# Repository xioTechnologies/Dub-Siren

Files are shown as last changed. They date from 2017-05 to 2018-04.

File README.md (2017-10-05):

# Dub Siren

A monophonic synthesiser comprised of an LFO, VCO, and Delay.  The synthesiser is controlled by 9 potentiometers and 3 buttons.  Configurations can be stored to 1 of 10 preset keys.  Pressing a preset key will override the potentiometers and buttons with the stored configuration.

The processor used is [PIC32MZ](http://www.microchip.com/wwwproducts/en/PIC32MZ2048EFH064).  This is a 32-bit device with a FPU, 512 KB of RAM, 2 MB of program space, running at 252 MHz.  The processor is deliberately over-spec'd to simplify development and allow new ideas to be explored in the future.  The [DAC](https://www.cirrus.com/products/cs4354/) is a 24-bit 192 kHz stereo device configured for 96 kHz mono.

## Synthesiser elements

##### LFO
- Waveforms: sine, triangle, sawtooth, square, stepped triangle, stepped sawtooth
- Shape: adjusts waveform shape
- Frequency: 0 Hz to 15 Hz
- Amplitude: -1 to +1
- Gate control: enable/disable (automatically opens gate after one cycle)

##### VCO
- Waveforms: sine, triangle, sawtooth, square, pulse, 1-bit noise
- Frequency: 0.5 Hz to 5 kHz

##### Delay
- Time: 0 s to 1.33 s
- Feedback: 0% to 100%
- Filter: 3rd-order low-pass with adjustable corner frequency, all-pass (filter disabled), 3rd-order high-pass with adjustable corner frequency

## User instructions (etched on the back panel)

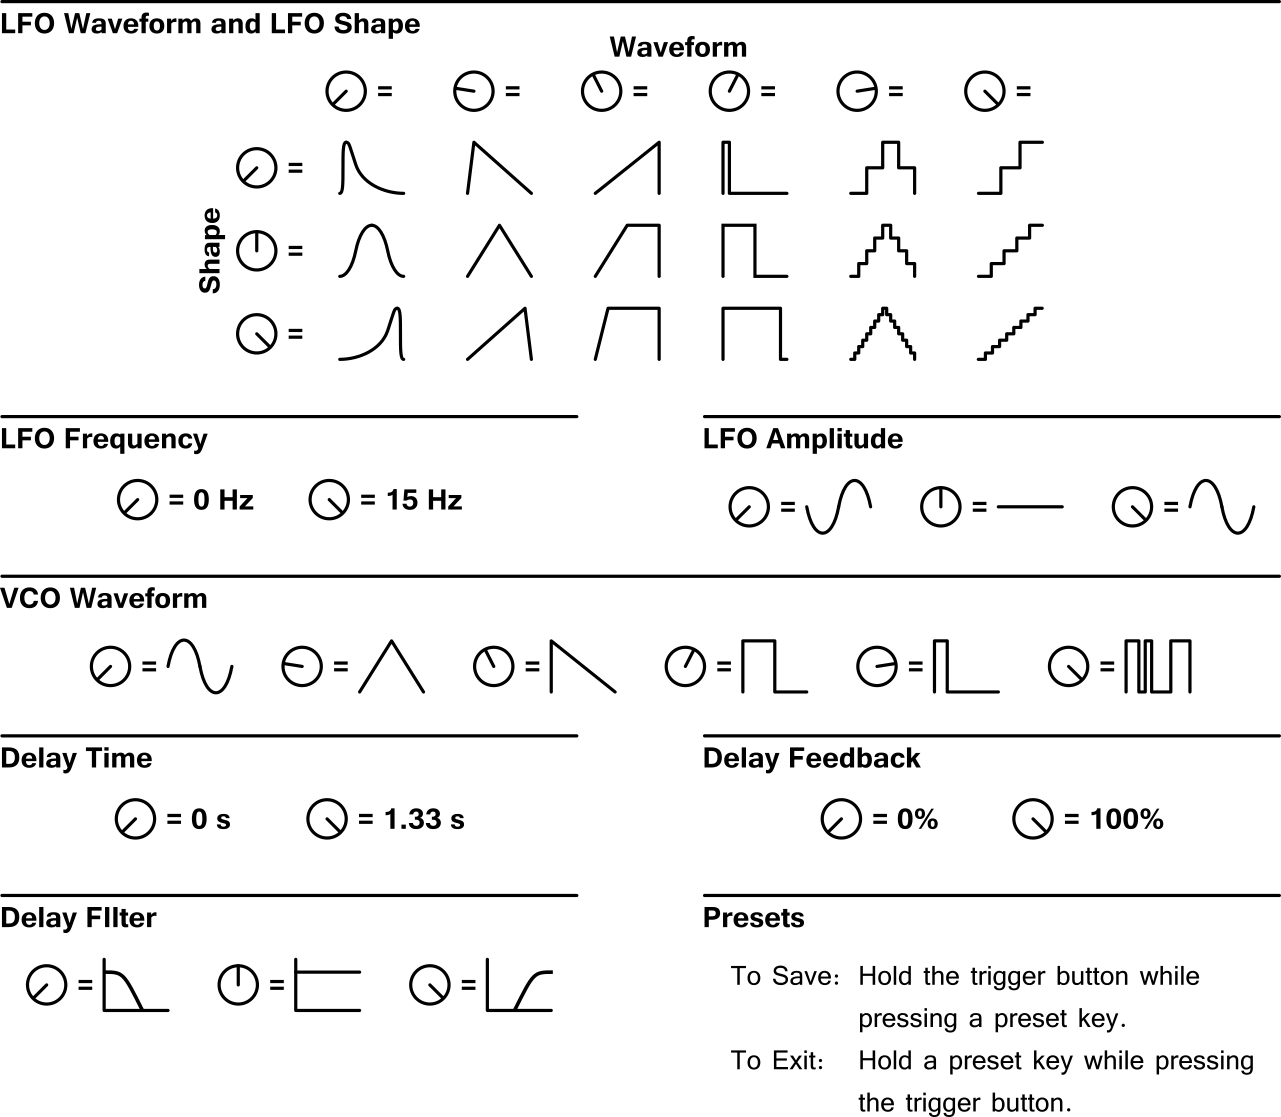
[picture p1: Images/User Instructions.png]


## BOM

* PCBA
* Top plate
* Bottom plate
* Spacer (x4)
* [Row 1, Size 1x1 Cherry MX Keycap](http://www.maxkeyboard.com/row-1-size-1x1-cherry-mx-keycap-r1-1x1.html) (x10)
* [8mm hex stand-off](https://www.digikey.co.uk/products/en?keywords=36-24432-ND) (x4)
* [M3 5mm screw](http://www.ebay.co.uk/itm/M3-BLACK-HIGH-TENSILE-10-9-BUTTON-HEAD-ALLEN-BOLTS-SELF-COLOUR-DOME-SOCKET-SCREW/121829578789) (x4)
* [M3 10mm screw](http://www.ebay.co.uk/itm/M3-BLACK-HIGH-TENSILE-10-9-BUTTON-HEAD-ALLEN-BOLTS-SELF-COLOUR-DOME-SOCKET-SCREW/121829578789) (x4)
* [3M rubber feet](http://www.ebay.co.uk/itm/100x-Silicone-RUBBER-FEET-Bumpons-CLEAR-Round-Self-Adhesive-Anti-Slip-Circles-3M-/172636687398) (x4)

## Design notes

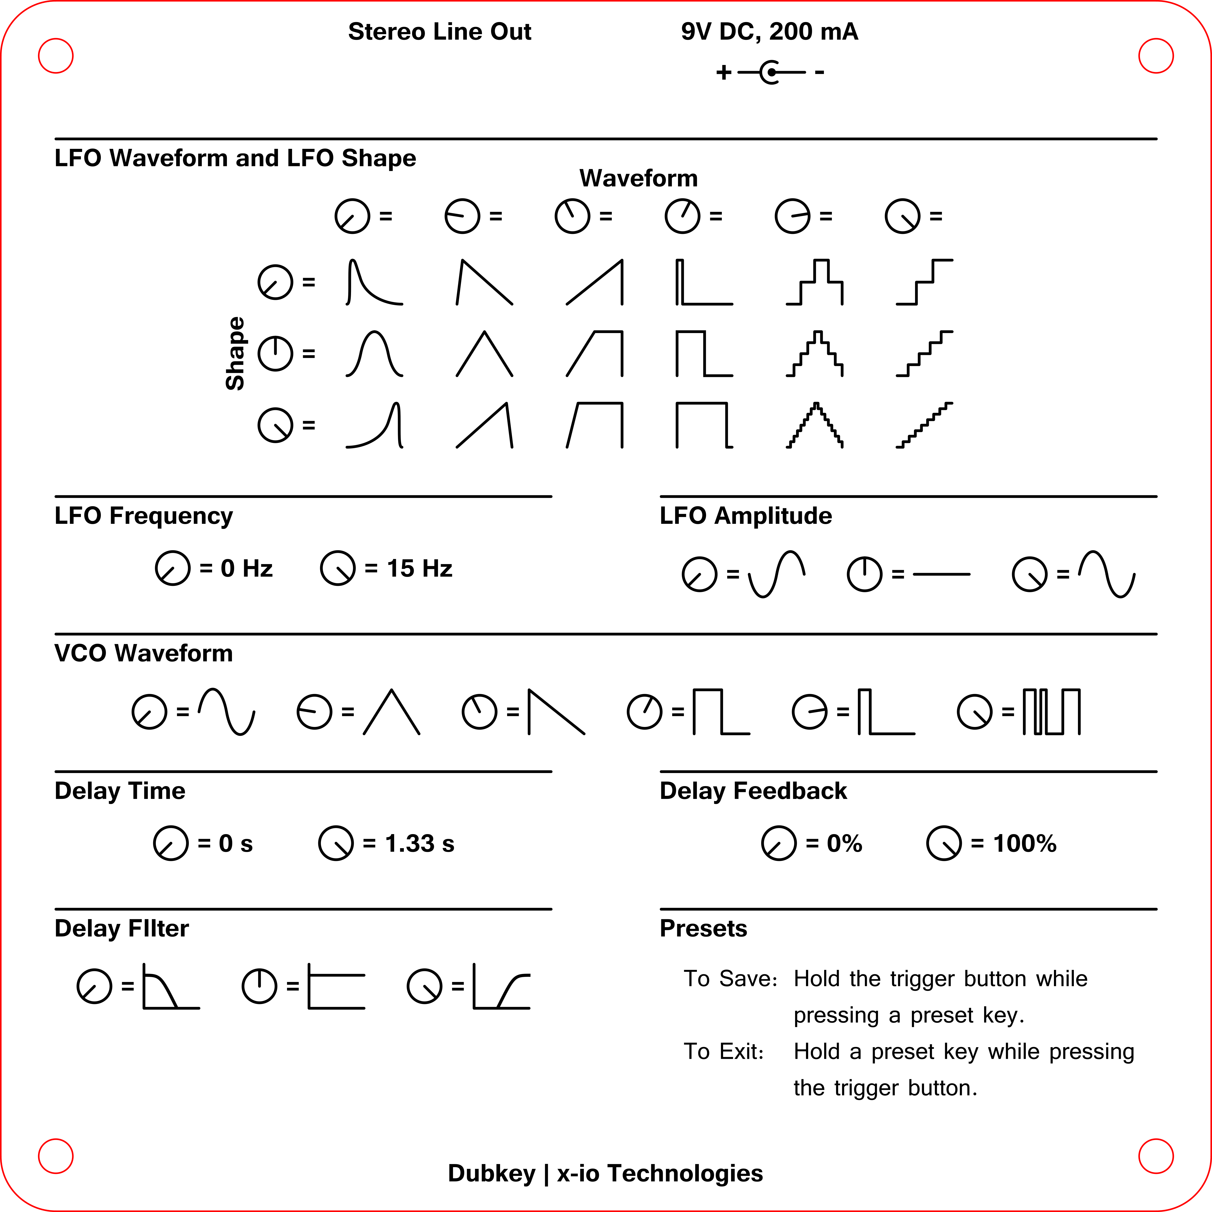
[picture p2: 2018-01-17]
Enclosure/Bottom Plate Decal.png

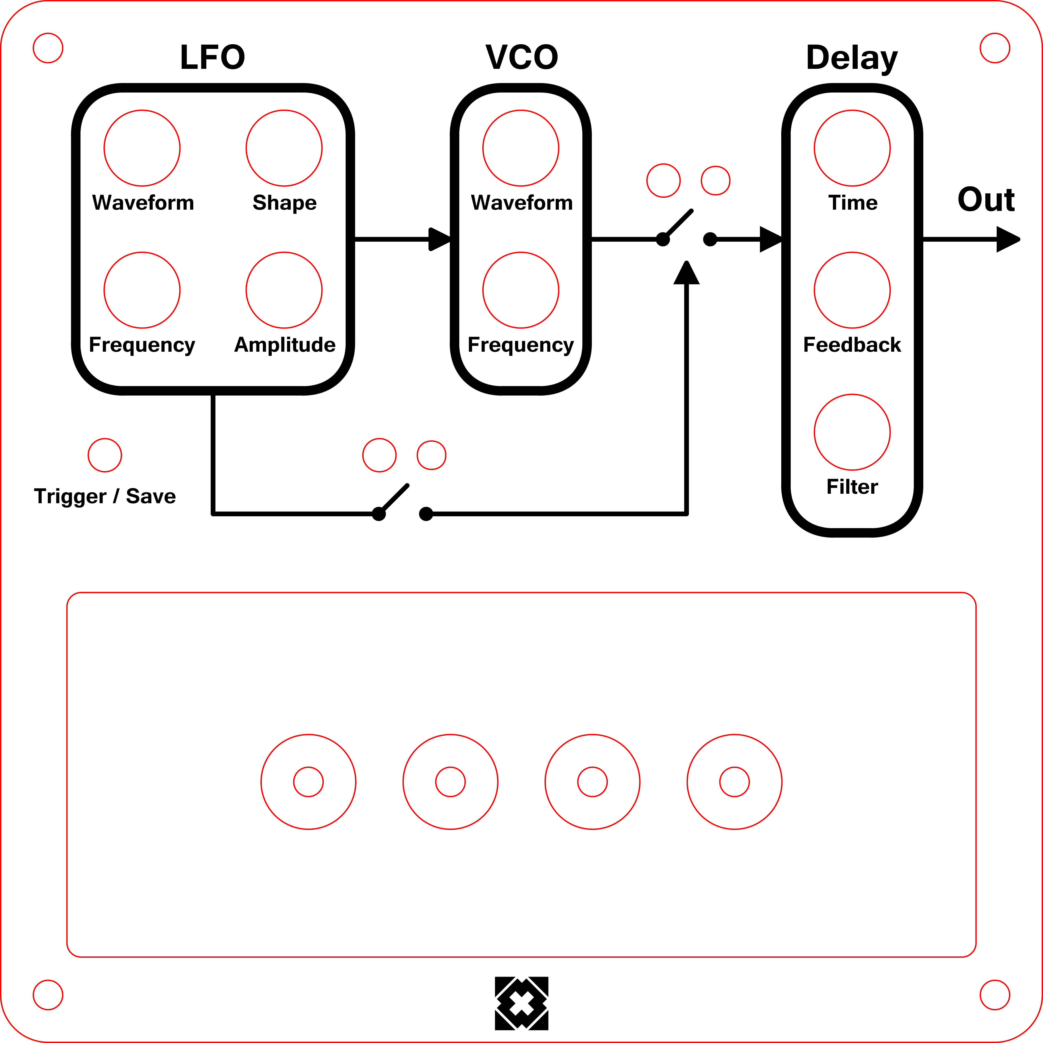
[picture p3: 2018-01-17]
Enclosure/Top Plate Decal.png

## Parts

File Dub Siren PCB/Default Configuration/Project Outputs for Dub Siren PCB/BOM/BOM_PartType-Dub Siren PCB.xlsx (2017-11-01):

Designator | Quantity | Comment | Footprint
C1, C2, C3, C4, C6, C7, C15, C17, C21 | 9 | 100n, 0603 | Capacitor 0603
C5, C8 | 2 | 22p, 0603 | Capacitor 0603
C9, C10, C11, C12, C13, C14, C16, C18 | 8 | 2u2, 0603 | Capacitor 0603
C19, C20 | 2 | 2n2, 0603 | Capacitor 0603
D1, D2 | 2 | WP424QR51WT/D-AMT | LED 3mm
D3 | 1 | SA1 | DO-214AC
J1 | 1 | PJ-051A | PJ-051A
J2 | 1 | SSW-116-02-G-D-RA | SSW-116-02-G-D-RA
J3 | 1 | SJ1-3525NG | SJ1-3525NG
R1, R2, R3, R13, R14 | 5 | 4k7, 0603 | Resistor 0603
R4, R5, R6, R7, R8, R9, R10, R11, R12 | 9 | RV09AF-40-20K-B10K | RV09ACF-40
R15, R16 | 2 | 470R, 0603 | Resistor 0603
S1, S2, S3, S4, S5, S6, S7, S8, S9, S10 | 10 | MX1A-E1NW | MX1A
S11, S12, S13 | 3 | FSM14JHX | FSM14JHX
U1 | 1 | PIC32MZ2048EFH064-I/PT | TQFP64
U2 | 1 | UA78M33CDCY | SOT-223
U3 | 1 | UA78M05CDCY | SOT-223
U4 | 1 | CS4354 | SOIC14
U5 | 1 | 24AA32A-I/SN | SOIC8
XT1 | 1 | ABM8-24.000MHZ-B2-T | ABM8

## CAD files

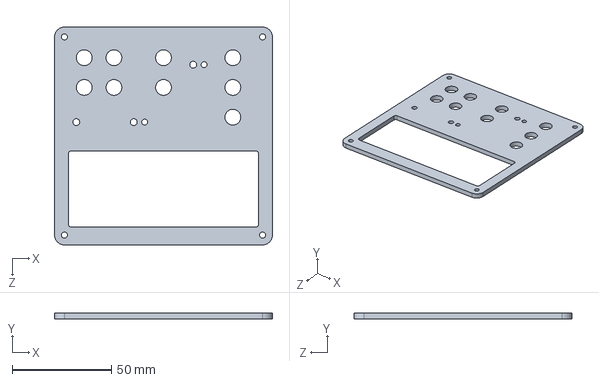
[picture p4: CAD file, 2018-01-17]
Enclosure/Top Plate.SLDPRT
110.0 x 3.00 x 110.0 mm

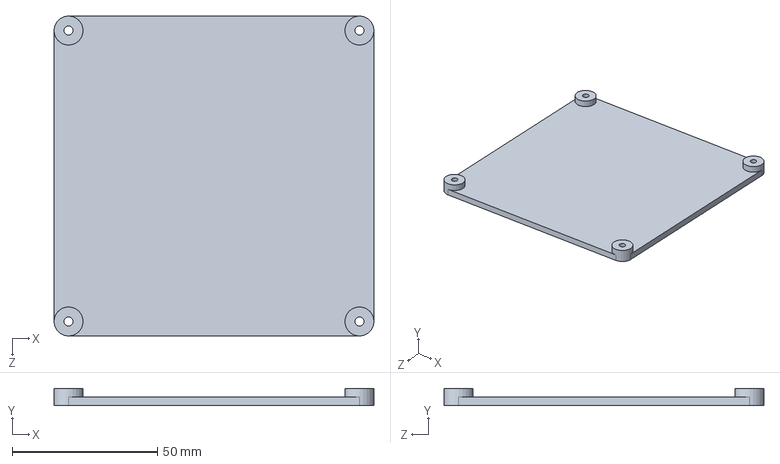
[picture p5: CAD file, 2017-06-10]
Enclosure/Bottom Plate.SLDPRT
110.0 x 6.00 x 110.0 mm

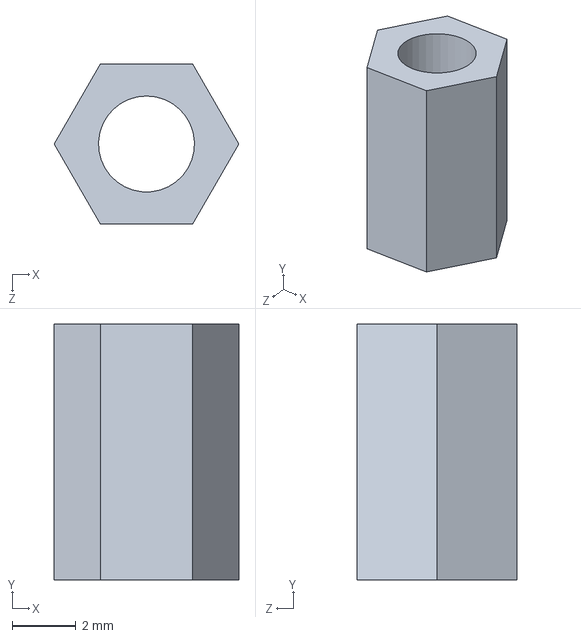
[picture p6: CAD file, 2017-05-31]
Enclosure/Hex Spacer.SLDPRT
5.77 x 8.00 x 5.00 mm

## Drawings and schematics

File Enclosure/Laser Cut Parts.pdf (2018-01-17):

LFO | VCO | Delay

## Out

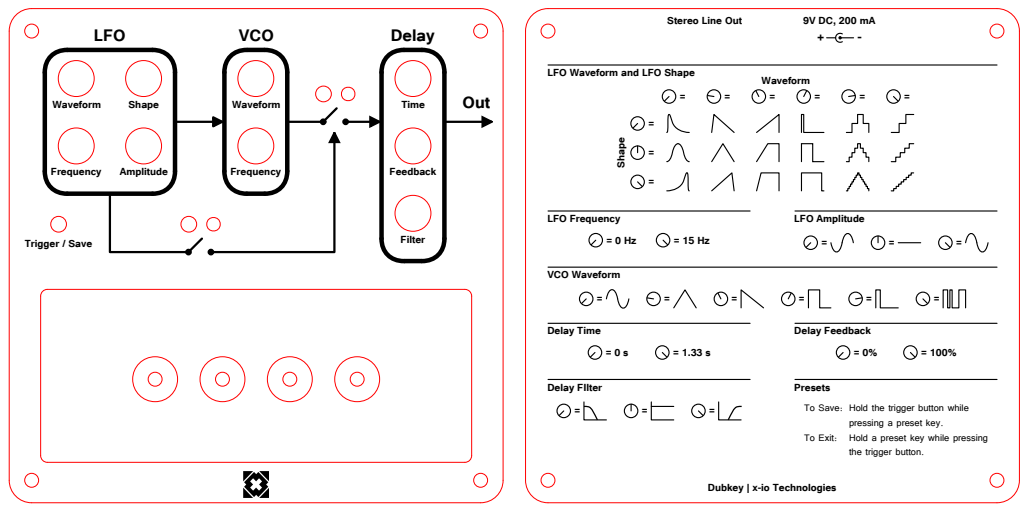
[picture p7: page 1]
Waveform; Shape; Frequency Amplitude; Frequency; Time; Feedback; Filter; Trigger / Save; LFO Frequency; VCO Waveform; LFO Amplitude; Delay Time; Delay Feedback; Delay FIlter; Presets; Stereo Line Out; = Shape

LFO Waveform and LFO Shape

To Save:
Hold the trigger button while
pressing a preset key.
To Exit:
Hold a preset key while pressing
the trigger button.

Dubkey | x-io Technologies

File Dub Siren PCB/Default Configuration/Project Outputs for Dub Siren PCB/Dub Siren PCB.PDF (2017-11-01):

Designator | Quantity | Comment | Footprint
C1, C2, C3, C4, C6, C7, C15, C17, C21 | 9 | 100n, 0603 | Capacitor 0603
C5, C8 | 2 | 22p, 0603 | Capacitor 0603
C9, C10, C11, C12, C13, C14, C16, C18 | 8 | 2u2, 0603 | Capacitor 0603
C19, C20 | 2 | 2n2, 0603 | Capacitor 0603
D1, D2 | 2 | WP424QR51WT/D-AMT | LED 3mm
D3 | 1 | SA1 | DO-214AC
J1 | 1 | PJ-051A | PJ-051A
J2 | 1 | SSW-116-02-G-D-RA | SSW-116-02-G-D-RA
J3 | 1 | SJ1-3525NG | SJ1-3525NG
R1, R2, R3, R13, R14 | 5 | 4k7, 0603 | Resistor 0603
R4, R5, R6, R7, R8, R9, R10, R11, R12 | 9 | RV09AF-40-20K-B10K | RV09ACF-40
R15, R16 | 2 | 470R, 0603 | Resistor 0603
S1, S2, S3, S4, S5, S6, S7, S8, S9, S10 | 10 | MX1A-E1NW | MX1A
S11, S12, S13 | 3 | FSM14JHX | FSM14JHX
U1 | 1 | PIC32MZ2048EFH064-I/PT | TQFP64
U2 | 1 | UA78M33CDCY | SOT-223
U3 | 1 | UA78M05CDCY | SOT-223
U4 | 1 | CS4354 | SOIC14
U5 | 1 | 24AA32A-I/SN | SOIC8
XT1 | 1 | ABM8-24.000MHZ-B2-T | ABM8

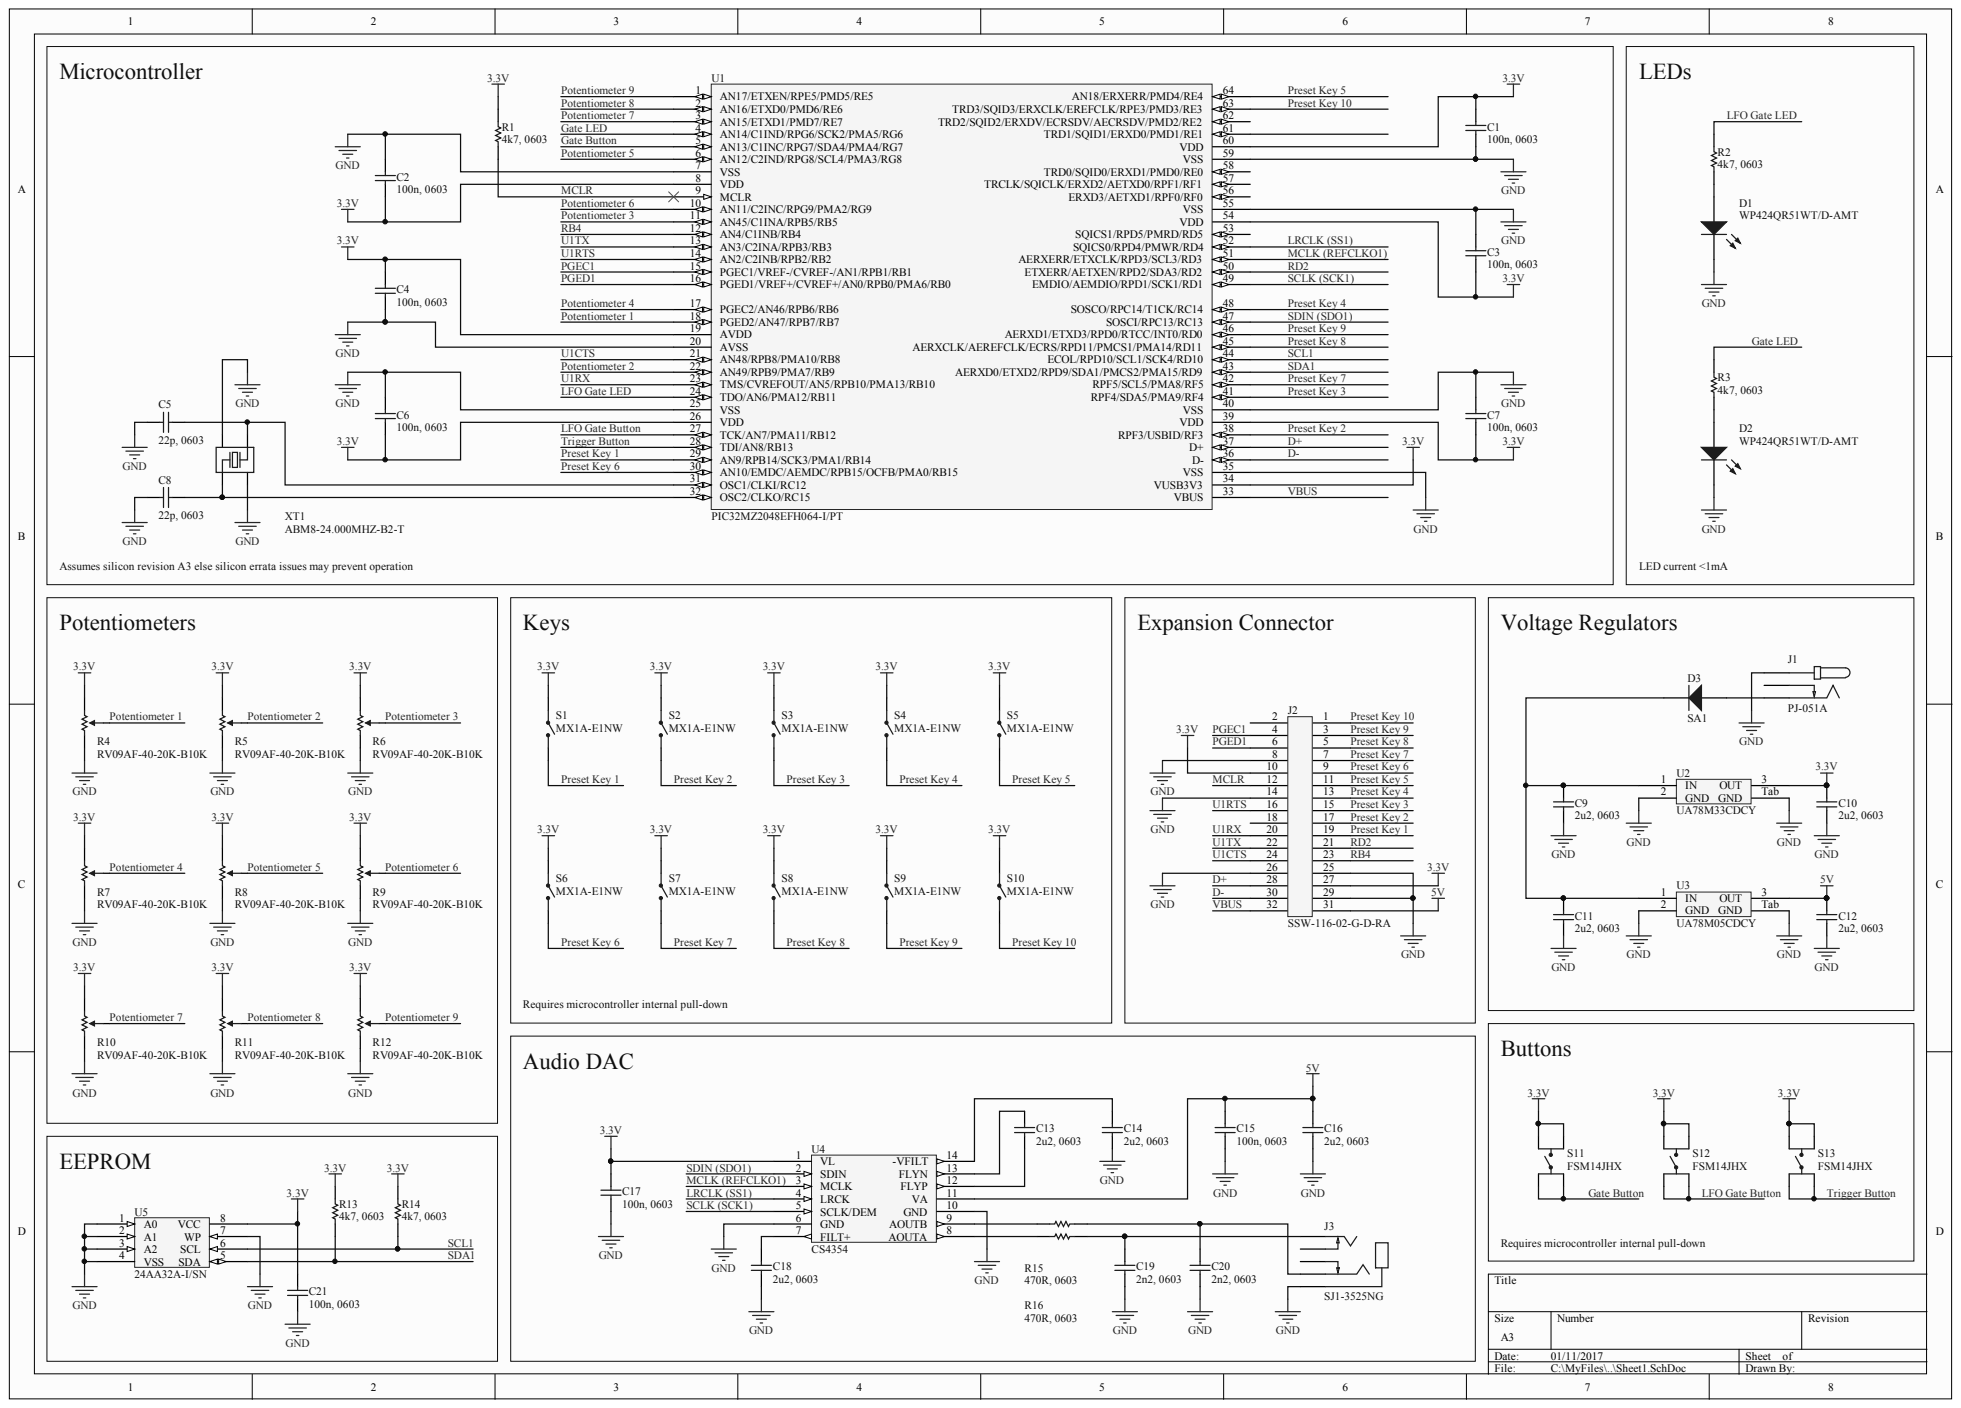
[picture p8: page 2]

Microcontroller Assumes silicon revision A3 el

Preset Key 1 Trigger Button LFO Gate Button U1CTS LFO Gate LED
iometer 2
Potent

sues may prevent operat

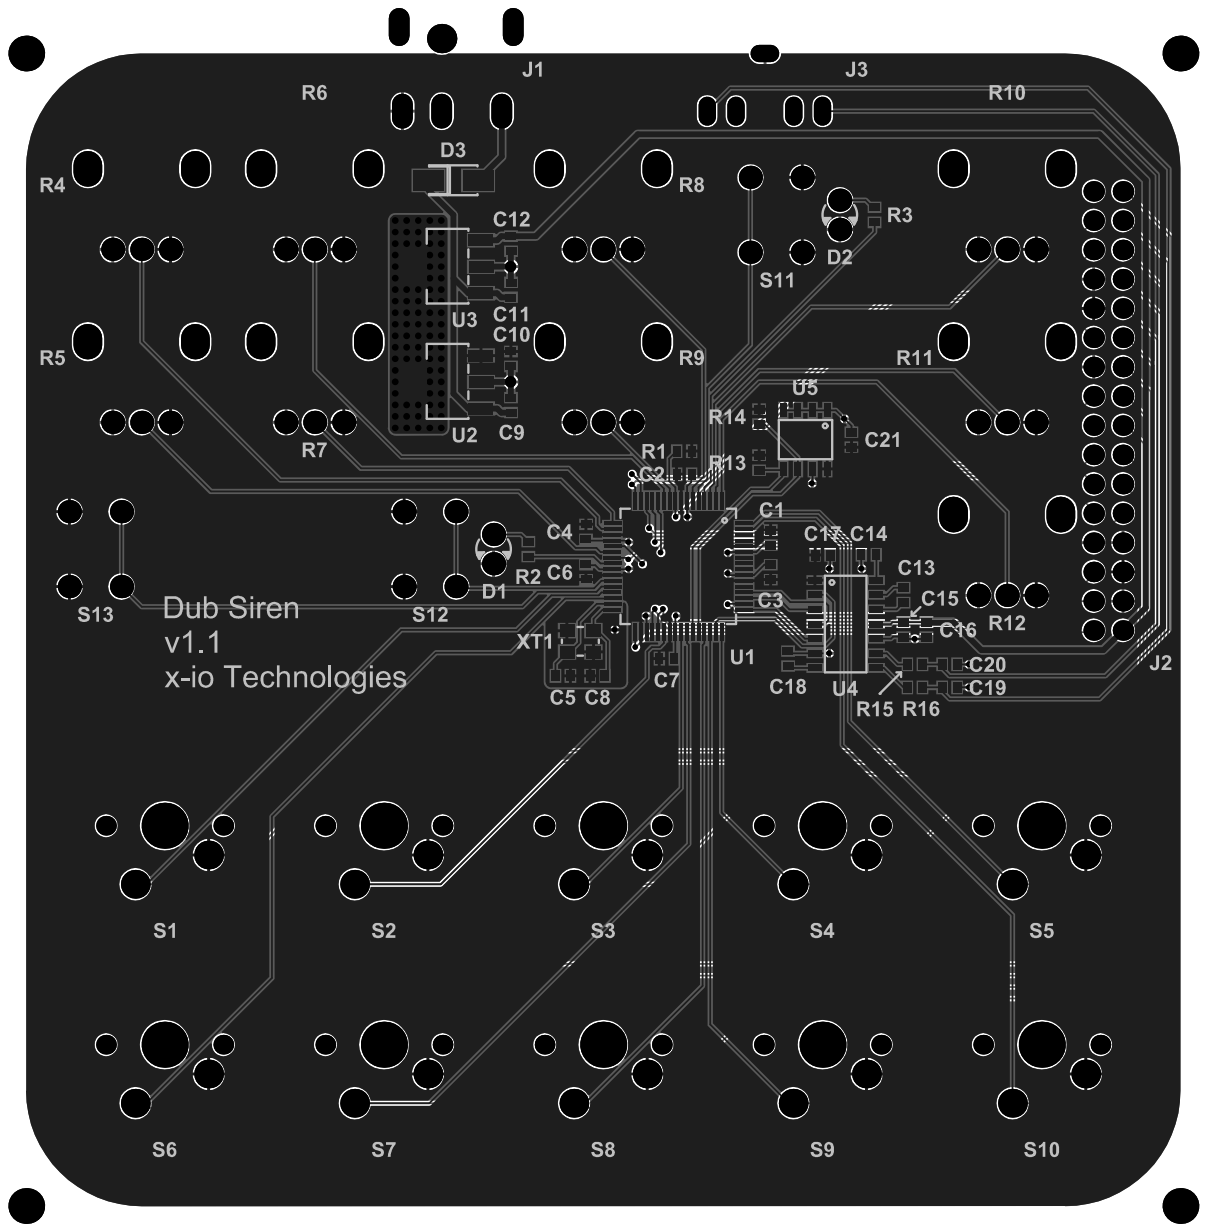
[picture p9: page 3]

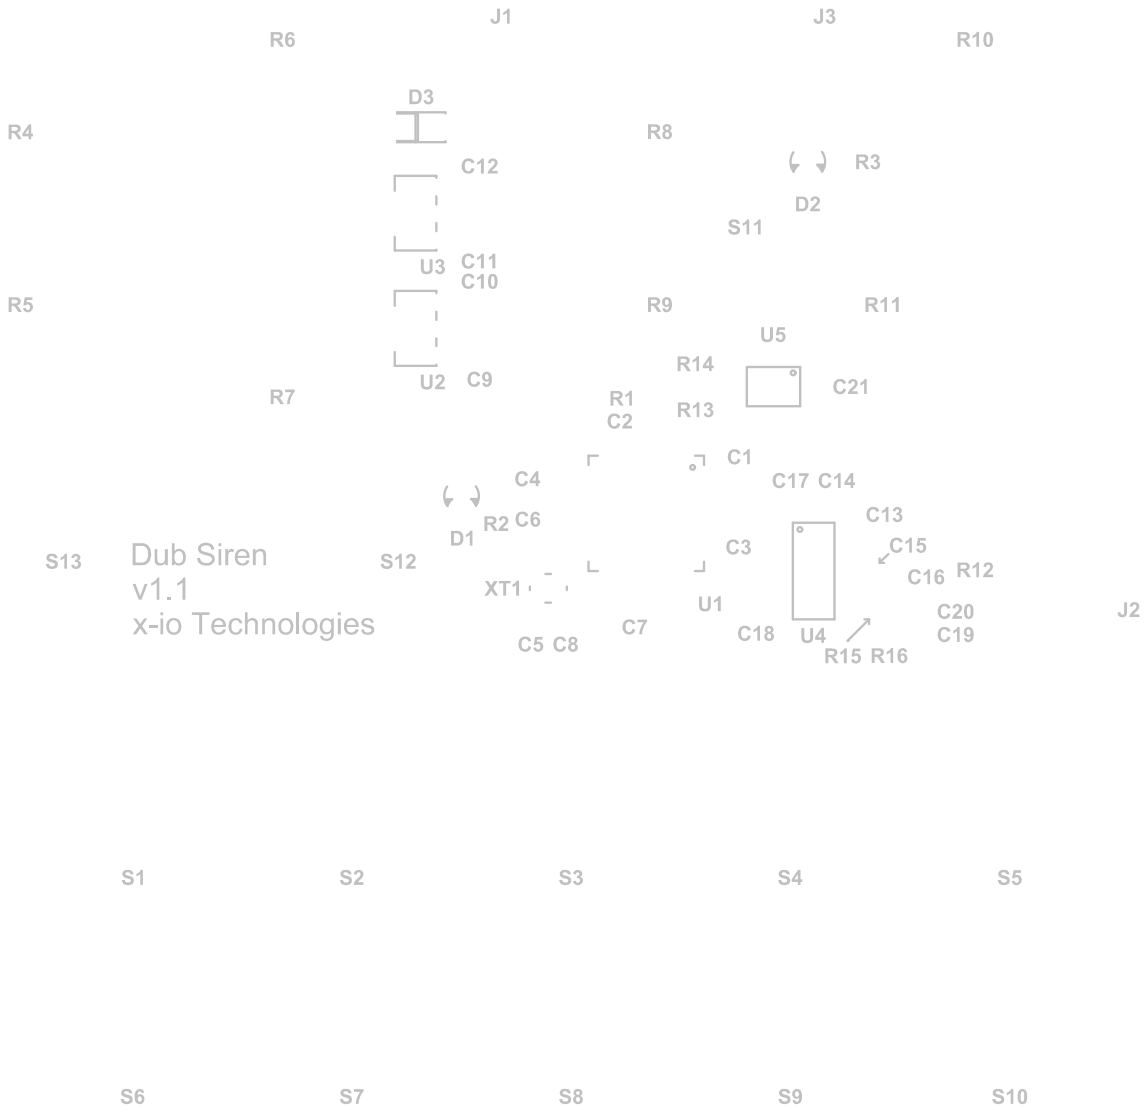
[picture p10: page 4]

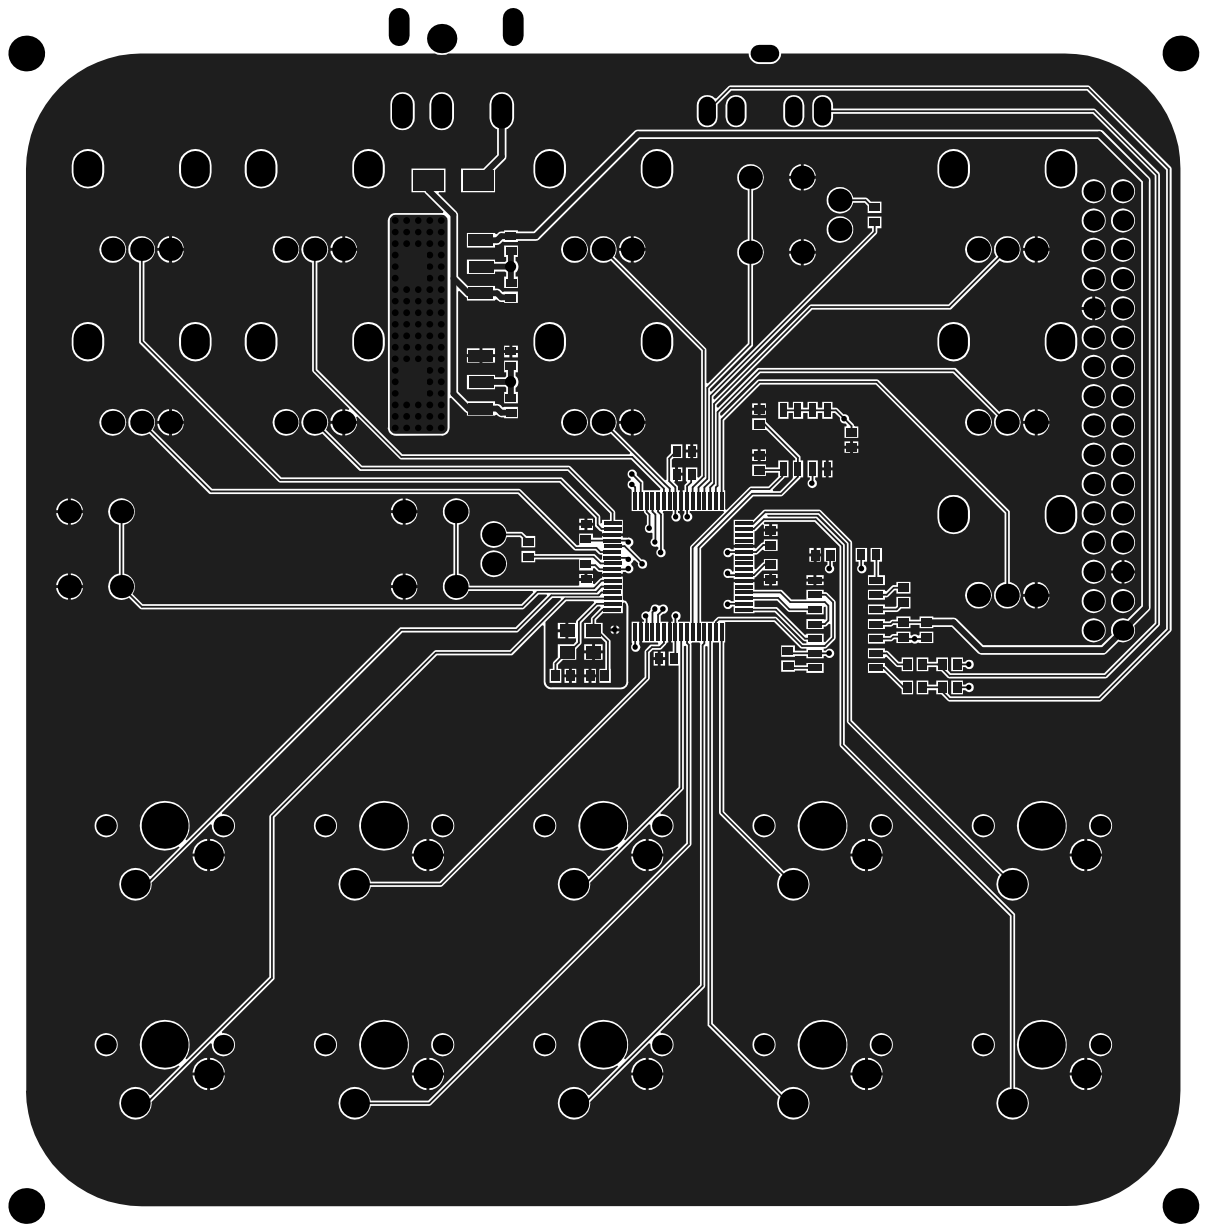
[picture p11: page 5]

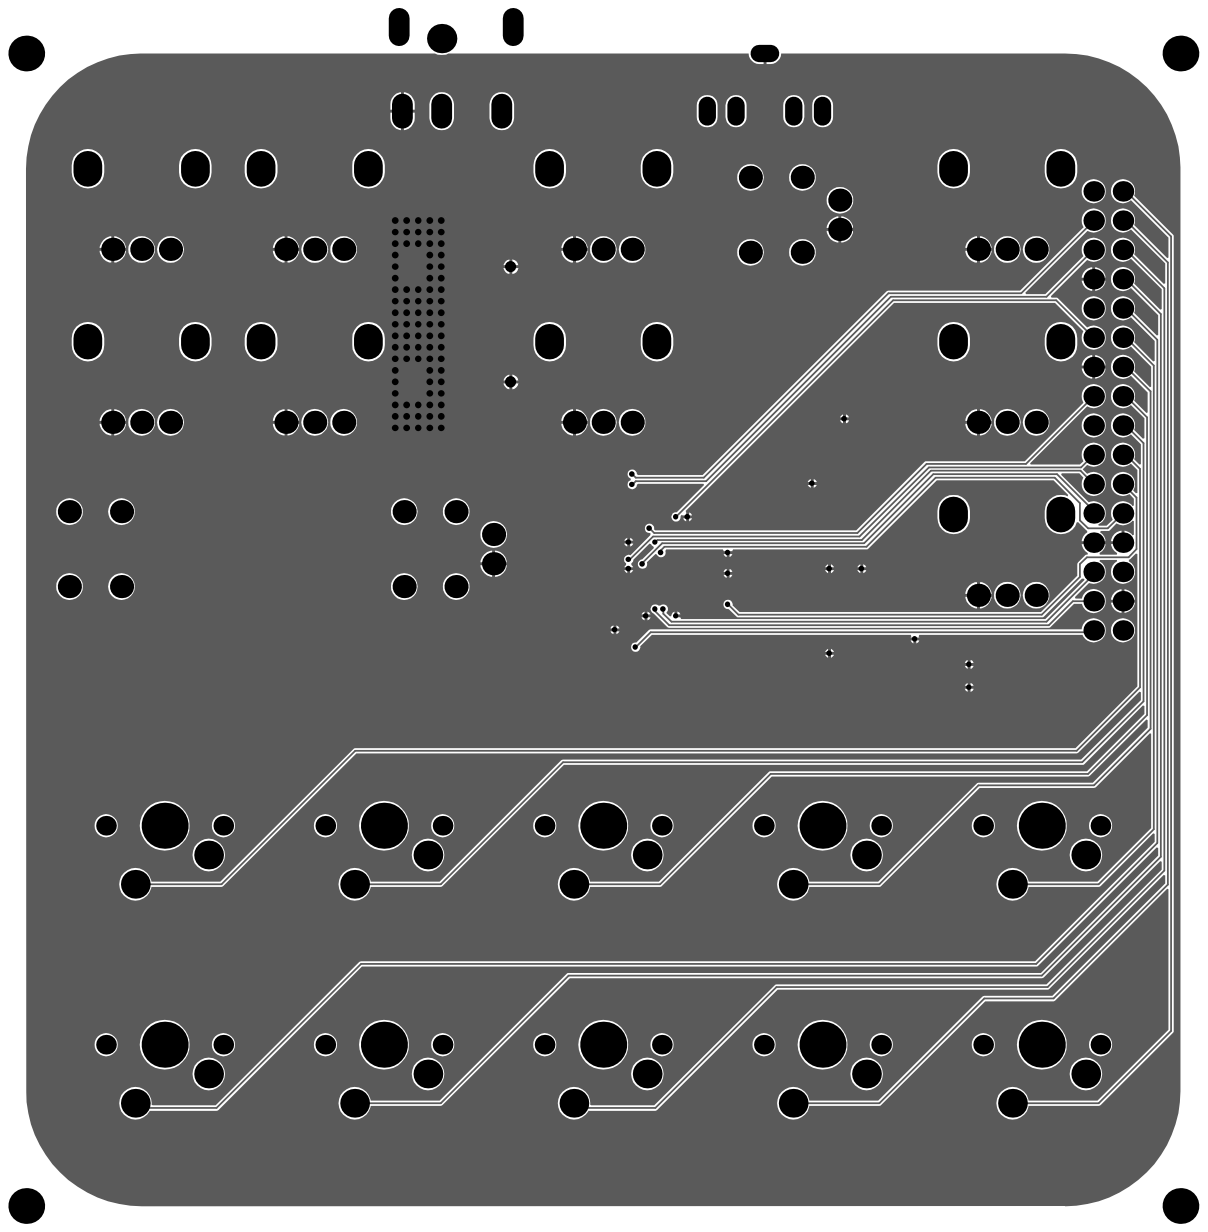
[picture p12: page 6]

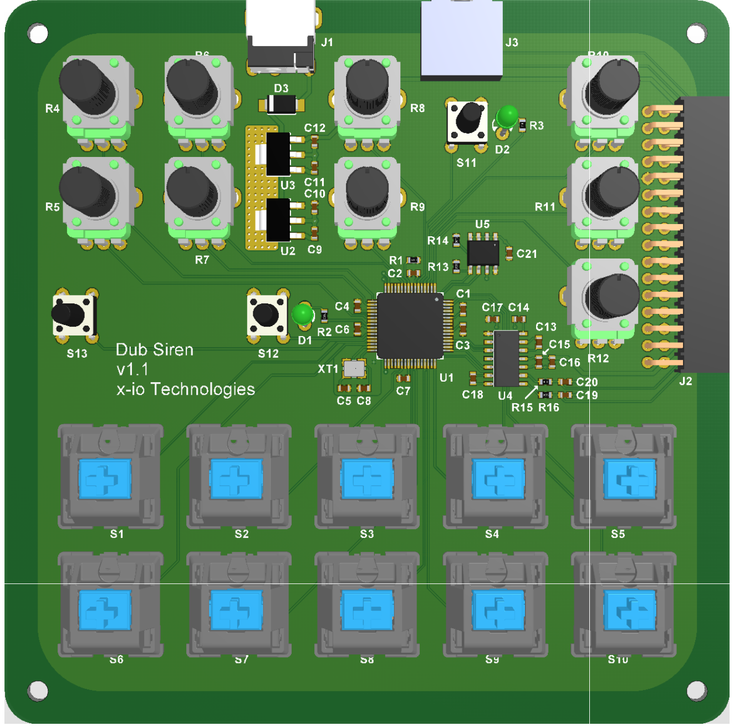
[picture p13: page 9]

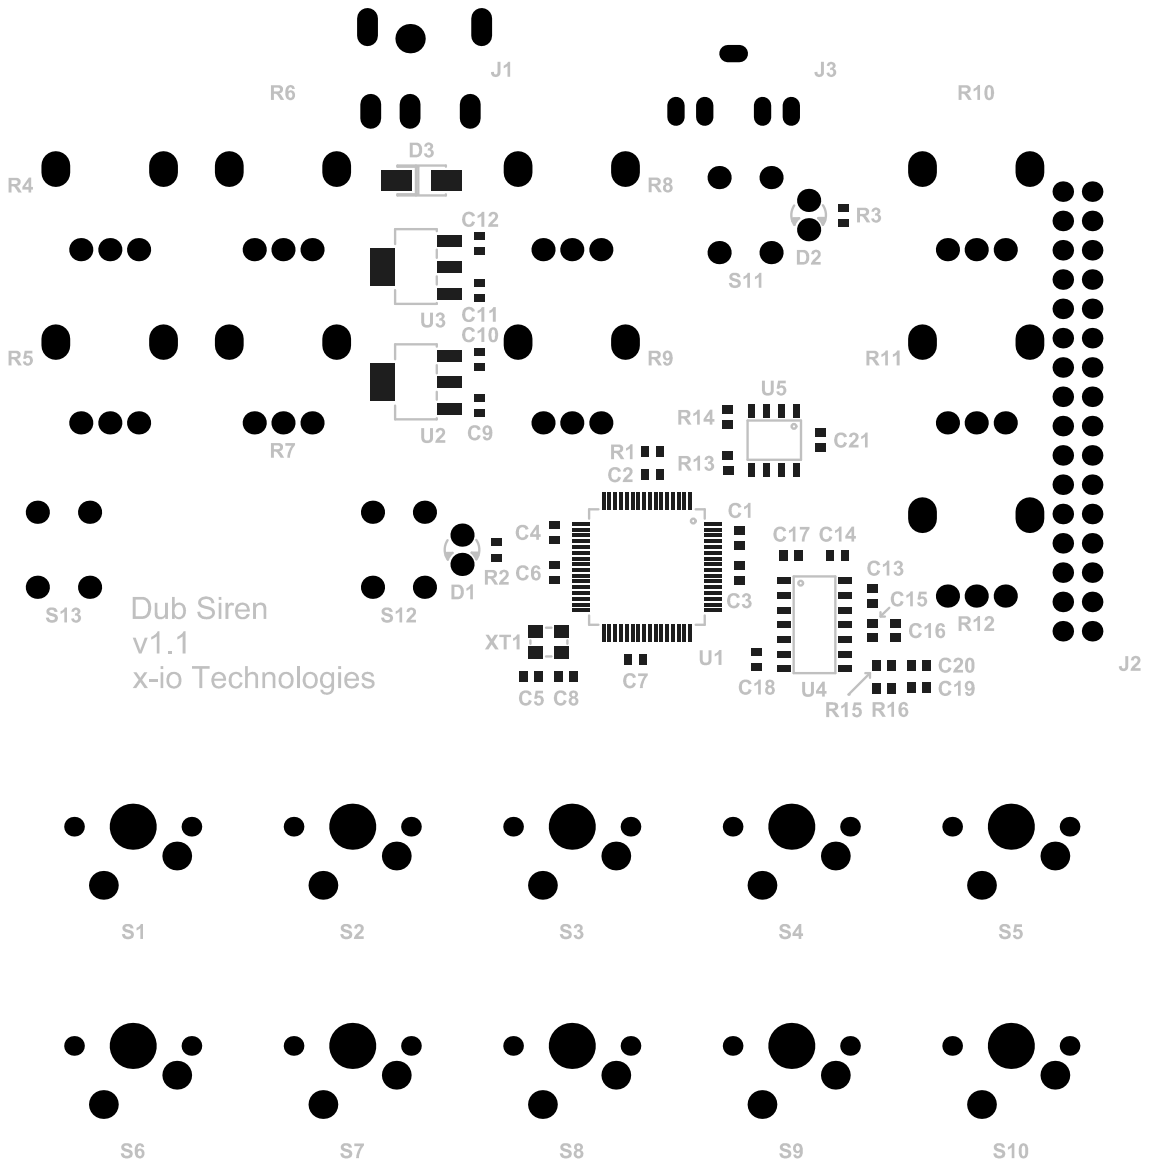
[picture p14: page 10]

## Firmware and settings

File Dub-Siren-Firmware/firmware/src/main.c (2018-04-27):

/**
 * @file Main.c
 * @author Seb Madgwick
 * @brief Firmware main file.
 *
 * Device:
 * PIC32MZ2048EFH064
 *
 * Compiler:
 * XC32 v2.05 (using Legacy libc), MPLAB Harmony v2.05.01
 */

//------------------------------------------------------------------------------
// Includes

#include "FirmwareVersion.h"
#include "IODefinitions.h"
#include <stdbool.h>
#include <stddef.h> // NULL
#include "Synthesiser/Synthesiser.h"
#include "system/common/sys_module.h" // SYS_Initialize
#include "Timer/Timer.h"
#include "Uart/Uart1.h"
#include "UserInterface/UserInterface.h"
#include <xc.h>

//------------------------------------------------------------------------------
// Function prototypes

static void Initialise();

//------------------------------------------------------------------------------
// Functions

/**
 * @brief Firmware entry point.
 * @return This function should never return.
 */
int main() {

    Initialise();

    TimerInitialise();

    Uart1Initialise(&defaultUartSettings);
    TimerDelay(1); // wait else first data may be corrupted
    Uart1WriteStringIfReady(
            "\r\n"
            "FIRMWARE VERSION:\r\n"
            FIRMWARE_VERSION
            "\r\n");

    SynthesiserInitialise();

    UserInterfaceInitialise();

    // Main program loop
    while (true) {
        UserInterfaceTasks();
    }
}

/**
 * @brief Initialise CPU and I/O.
 */
static void Initialise() {

    // Configure system clock and enable interrupts using MPLAB Harmony
    SYS_Initialize(NULL);

    // Disable all analogue inputs
    ANSELB = 0x00000000;
    ANSELE = 0x00000000;
    ANSELG = 0x00000000;

    // Enable all pull-downs
    CNPDB = 0xFFFFFFFF;
    CNPDC = 0xFFFFFFFF;
    CNPDD = 0xFFFFFFFF;
    CNPDE = 0xFFFFFFFF;
    CNPDF = 0xFFFFFFFF;
    CNPDG = 0xFFFFFFFF;

    // Configure analogue inputs I/O
    POTENTIOMETER_1_ANSEL = 1;
    POTENTIOMETER_1_CNPD = 0;
    POTENTIOMETER_2_ANSEL = 1;
    POTENTIOMETER_2_CNPD = 0;
    POTENTIOMETER_3_ANSEL = 1;
    POTENTIOMETER_3_CNPD = 0;
    POTENTIOMETER_4_ANSEL = 1;
    POTENTIOMETER_4_CNPD = 0;
    POTENTIOMETER_5_ANSEL = 1;
    POTENTIOMETER_5_CNPD = 0;
    POTENTIOMETER_6_ANSEL = 1;
    POTENTIOMETER_6_CNPD = 0;
    POTENTIOMETER_7_ANSEL = 1;
    POTENTIOMETER_7_CNPD = 0;
    POTENTIOMETER_8_ANSEL = 1;
    POTENTIOMETER_8_CNPD = 0;
    POTENTIOMETER_9_ANSEL = 1;
    POTENTIOMETER_9_CNPD = 0;

    // Configure LED I/O
    LFO_GATE_CONTROL_LED_TRIS = 0;
    GATE_LED_TRIS = 0;

    // Configure DAC I/O
    DAC_REFCLKO_MAP();
    DAC_SDO_MAP();
    DAC_SS_MAP();

    // Configure EEPROM I/O
    EEPROM_SCL_TRIS = 0;
    EEPROM_SCL_LAT = 1;
    EEPROM_SCL_ODC = 1;
    EEPROM_SCL_CNPD = 0;
    EEPROM_SDA_TRIS = 0;
    EEPROM_SDA_LAT = 1;
    EEPROM_SDA_ODC = 1;
    EEPROM_SDA_CNPD = 0;

    // Configure UART I/O
    UART_RX_MAP();
    UART_TX_MAP();
    UART_RTS_MAP();
    UART_CTS_MAP();
}

//------------------------------------------------------------------------------
// End of file

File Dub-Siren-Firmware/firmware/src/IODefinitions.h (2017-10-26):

/**
 * @file IODefinitions.h
 * @author Seb Madgwick
 * @brief I/O definitions.
 */

#ifndef IO_DEFINITIONS_H
#define IO_DEFINITIONS_H

//------------------------------------------------------------------------------
// Includes

#include <xc.h>

//------------------------------------------------------------------------------
// Definitions

// Analogue inputs
#define POTENTIOMETER_1_ANSEL               ANSELBbits.ANSB7 /* AN47 */
#define POTENTIOMETER_1_CNPD                CNPDBbits.CNPDB7
#define POTENTIOMETER_2_ANSEL               ANSELBbits.ANSB9 /* AN49 */
#define POTENTIOMETER_2_CNPD                CNPDBbits.CNPDB9
#define POTENTIOMETER_3_ANSEL               ANSELBbits.ANSB5 /* AN45 */
#define POTENTIOMETER_3_CNPD                CNPDBbits.CNPDB5
#define POTENTIOMETER_4_ANSEL               ANSELBbits.ANSB6 /* AN46 */
#define POTENTIOMETER_4_CNPD                CNPDBbits.CNPDB6
#define POTENTIOMETER_5_ANSEL               ANSELGbits.ANSG8 /* AN12 */
#define POTENTIOMETER_5_CNPD                CNPDGbits.CNPDG8
#define POTENTIOMETER_6_ANSEL               ANSELGbits.ANSG9 /* AN11 */
#define POTENTIOMETER_6_CNPD                CNPDGbits.CNPDG9
#define POTENTIOMETER_7_ANSEL               ANSELEbits.ANSE7 /* AN15 */
#define POTENTIOMETER_7_CNPD                CNPDEbits.CNPDE7
#define POTENTIOMETER_8_ANSEL               ANSELEbits.ANSE6 /* AN16 */
#define POTENTIOMETER_8_CNPD                CNPDEbits.CNPDE6
#define POTENTIOMETER_9_ANSEL               ANSELEbits.ANSE5 /* AN17 */
#define POTENTIOMETER_9_CNPD                CNPDEbits.CNPDE5

// Buttons
#define TRIGGER_SAVE_BUTTON_PORT            PORTB
#define TRIGGER_SAVE_BUTTON_PORT_BIT        (13)
#define LFO_GATE_CONTROL_BUTTON_PORT        PORTB
#define LFO_GATE_CONTROL_BUTTON_PORT_BIT    (12)
#define GATE_BUTTON_PORT                    PORTG
#define GATE_BUTTON_PORT_BIT                (7)
#define PRESET_KEY_1_PORT                   PORTB
#define PRESET_KEY_1_PORT_BIT               (14)
#define PRESET_KEY_2_PORT                   PORTF
#define PRESET_KEY_2_PORT_BIT               (3)
#define PRESET_KEY_3_PORT                   PORTF
#define PRESET_KEY_3_PORT_BIT               (4)
#define PRESET_KEY_4_PORT                   PORTC
#define PRESET_KEY_4_PORT_BIT               (14)
#define PRESET_KEY_5_PORT                   PORTE
#define PRESET_KEY_5_PORT_BIT               (4)
#define PRESET_KEY_6_PORT                   PORTB
#define PRESET_KEY_6_PORT_BIT               (15)
#define PRESET_KEY_7_PORT                   PORTF
#define PRESET_KEY_7_PORT_BIT               (5)
#define PRESET_KEY_8_PORT                   PORTD
#define PRESET_KEY_8_PORT_BIT               (11)
#define PRESET_KEY_9_PORT                   PORTD
#define PRESET_KEY_9_PORT_BIT               (0)
#define PRESET_KEY_10_PORT                  PORTE
#define PRESET_KEY_10_PORT_BIT              (3)

// LEDs
#define LFO_GATE_CONTROL_LED_TRIS           TRISBbits.TRISB11
#define LFO_GATE_CONTROL_LED_LAT            LATBbits.LATB11
#define GATE_LED_TRIS                       TRISGbits.TRISG6
#define GATE_LED_LAT                        LATGbits.LATG6

// DAC
#define DAC_REFCLKO_MAP()                   RPD3Rbits.RPD3R = 0b1111
#define DAC_SDO_MAP()                       RPC13Rbits.RPC13R = 0b0101
#define DAC_SS_MAP()                        RPD4Rbits.RPD4R = 0b0101

// EEPROM
#define EEPROM_SCL_TRIS                     TRISDbits.TRISD10
#define EEPROM_SCL_LAT                      LATDbits.LATD10
#define EEPROM_SCL_ODC                      ODCDbits.ODCD10
#define EEPROM_SCL_CNPD                     CNPDDbits.CNPDD10
#define EEPROM_SDA_TRIS                     TRISDbits.TRISD9
#define EEPROM_SDA_PORT                     PORTDbits.RD9
#define EEPROM_SDA_LAT                      LATDbits.LATD9
#define EEPROM_SDA_ODC                      ODCDbits.ODCD9
#define EEPROM_SDA_CNPD                     CNPDDbits.CNPDD9

// UART
#define UART_RX_MAP()                       U1RXRbits.U1RXR = 0b1010
#define UART_TX_MAP()                       RPB3Rbits.RPB3R = 0b0001
#define UART_RTS_MAP()                      RPB2Rbits.RPB2R = 0b0001
#define UART_CTS_MAP()                      U1CTSRbits.U1CTSR = 0b0010

#endif

//------------------------------------------------------------------------------
// End of file

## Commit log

2017-05-30 Commit PCB v1.0
    [Dub Siren PCB.PrjPcb, Sheet1.SchDoc, [Dub Siren PCB.PrjPcb] BOM_PartType-Dub Siren PCB.xlsx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]
2017-05-30 Update .OutJob file to include holes in step export
    [[Dub Siren PCB.PrjPcb] BOM_PartType-Dub Siren PCB.xlsx]
2017-05-31 Add enclosure files
    [Bottom Plate.SLDPRT, Hex Spacer.SLDPRT, Top Plate.SLDPRT]
2017-06-02 Add profile output pin
    [Sheet1.SchDoc]
2017-06-02 Swap potentiometers R8 and R9 for consistency
    [Sheet1.SchDoc]
2017-06-03 Swap left and right channel connections
    [Sheet1.SchDoc]
2017-06-08 Add PIC32MZ I2C documentation
2017-06-09 Adjust preset keys hole on top plate
    [Top Plate.SLDPRT]
2017-06-10 Add user instructions to bottom plate
    [Bottom Plate.SLDPRT]
2017-06-10 Change net names for consistency with firmware
    [Sheet1.SchDoc]
2017-06-11 Use 32K EEPROM instead of 8K
    [Sheet1.SchDoc]
2017-06-11 Add missing Bottom Plate Decal file
2017-06-14 Correct EEPROM datasheet file name and and I2C bus specification pdf
    [Dub Siren PCB.PrjPcb]
2017-06-14 Replace most resistors with 4k7 to decrease LED brightness and reduce BOM
    [Sheet1.SchDoc]
2017-06-14 Reduce LED hole diameter
    [Top Plate.SLDPRT]
2017-09-18 Fix bug that caused VCO frequency to underflow
    [UserInterface.c]
2017-10-05 Add key caps to BOM
2017-10-22 Add expansion header
    [Dub Siren PCB.PrjPcb, Sheet1.SchDoc]
2017-10-23 Tidy schematic and increment version in silkscreen text
    [Sheet1.SchDoc]
2017-10-23 Adjust routing to remove bottle neck in ground plane
    [Sheet1.SchDoc]
2017-10-23 Generate PCB project outputs
    [BOM_PartType-Dub Siren PCB.xlsx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]
2017-10-23 Update enclosure with latest PCBA step model
2017-10-23 Adjust routing for improved aesthetic
    [BOM_PartType-Dub Siren PCB.xlsx, Dub Siren PCB.PrjPcb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]
2017-10-26 Use MPLAB Harmony to interact with interrupt registers
2017-10-26 Refactor UART library
2017-10-26 Remove test pin I/O definitions
2017-10-26 Refactor Timer library
2017-10-26 Use -Wall and fix warnings
    [UserInterface.c, main.c]
2017-10-27 Change LED part number
    [Dub Siren PCB.PrjPcb, Sheet1.SchDoc]
2017-11-01 Change potentiometer part number
    [Sheet1.SchDoc]
2017-11-14 Refactor I2C library
2018-01-17 Increase potentiometer hole diameter
    [Top Plate.SLDPRT]
2018-02-27 Add .eps of Laser Cut Parts
2018-04-27 Modify UART library for compatibility with all PIC32 devices
